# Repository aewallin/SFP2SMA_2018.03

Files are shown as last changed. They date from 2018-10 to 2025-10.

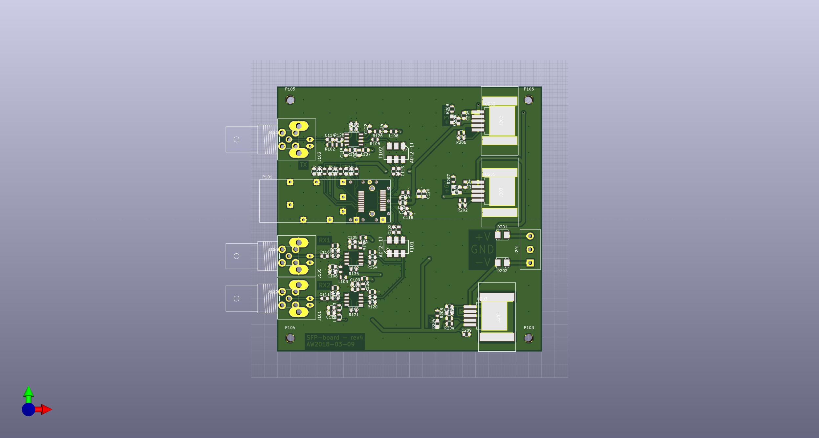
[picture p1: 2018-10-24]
doc/top_view.jpg

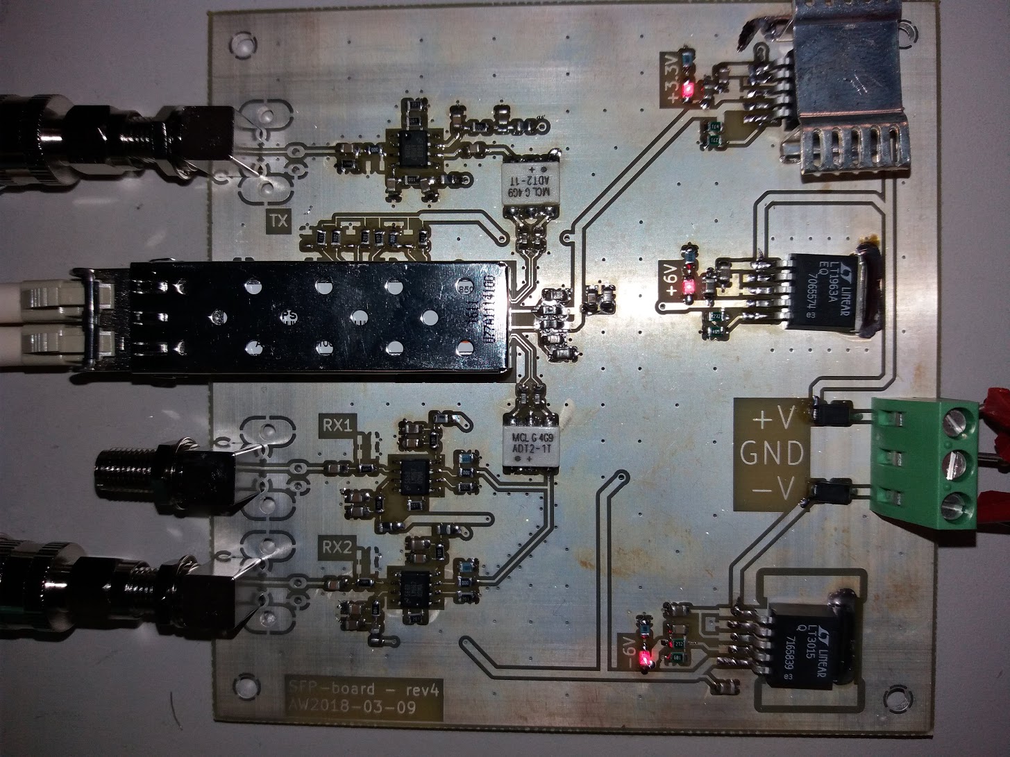
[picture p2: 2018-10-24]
doc/SFP-board_v4_20180403_162020.jpg

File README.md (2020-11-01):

# SFP-2-SMA Board, 2018-03

This is a simple board for opto/electric and electro/optic conversion of RF-signals (up to maybe 500 MHz)
using telecom SFP transcievers. The board can be fitted with either BNC or SMA connectors. It has one input
which modulates the TX pins of the SFP, and two identical outputs that represent the signal on the RX pins
of the SFP.

Some notes from 2018-04: http://www.anderswallin.net/2018/04/500-mhz-sfp-board-v4/

## Circuit description

Differential (100 Ohm) signals on the TX+/TX- and RX+/RX- pins of the SFP are converted to
single-ended (50 Ohm) signals using Mini-Circuits ADT2-1T transformers.
LMH6702 op-amps amplify/buffer all signals.
LT1963 and LT3015 low-noise LDOs provide +3V3, +6V, and -6V DC rails.
The +3V3 LDO needs heat-sinking, especially with long-range SFPs that have high current draw.

## Links to other SFP-boards

- https://osmocom.org/projects/misc-hardware/wiki/Sfp-experimenter
- https://osmocom.org/projects/misc-hardware/wiki/Sfp-breakout
- https://vksdr.com/pmod

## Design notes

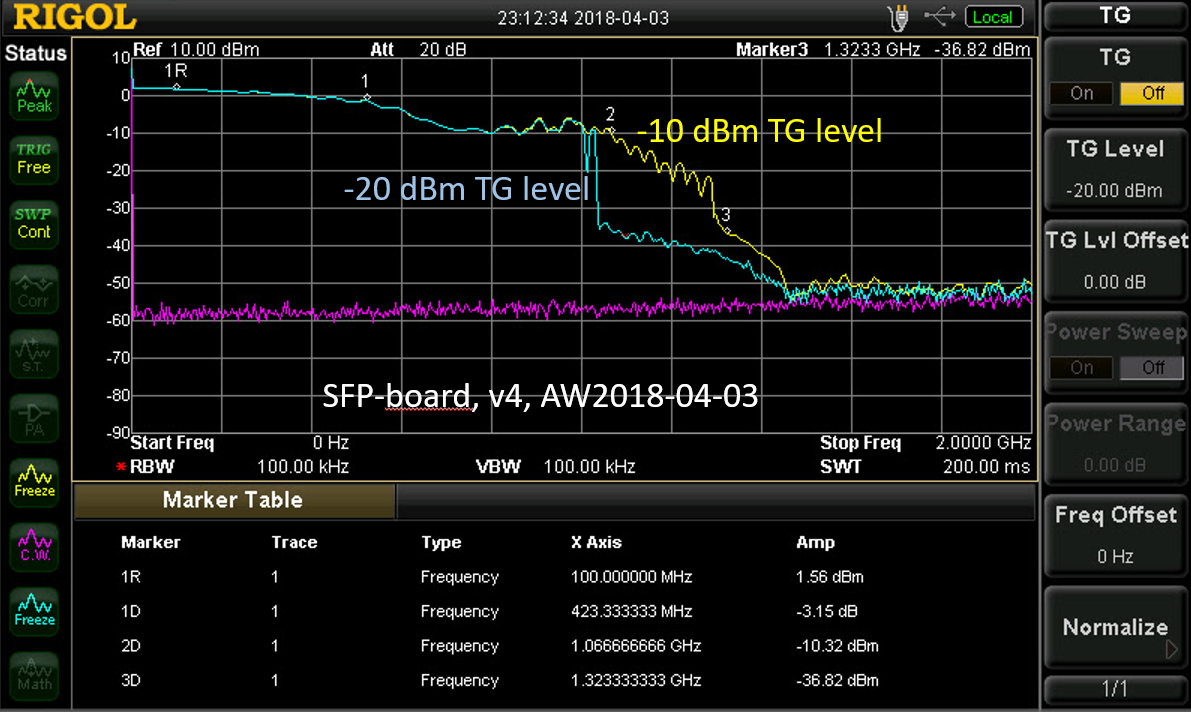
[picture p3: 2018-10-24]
doc/SFP-board_v4_2018-04-03.png

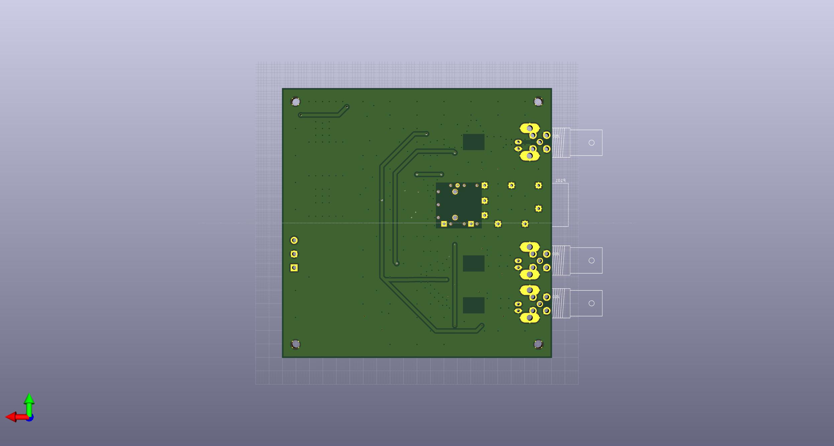
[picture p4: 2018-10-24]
doc/bot_view.jpg

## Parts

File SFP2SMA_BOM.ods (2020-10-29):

Description | QTY | price | total | Digikey/Farnell
Resistors, SMD 0805 | 20 |  | 0
Capacitors, SMD 0805 | 20 |  | 0
LED, SMD 0805 | 6 | 0.109 | 0.654 | 2463991
Inductor, SMD 0805 | 8 |  | 0
Diode, DO214B | 3 | 0.3 | 0.9 | 9555986
Heatsink, D2PAK | 1 | 1.66 | 1.66 | 4302436
SMA connectors | 3 | 4.97 | 14.91 | 2293854
DC-connector, 4pole | 1 | 1.89 | 1.89 | 277-1249-ND
SFP-connector | 1 | 1.64 | 1.64 | 1654067
SFP-cage | 1 | 1.55 | 1.55 | 1849934
RF Transformer, ADT2-1T | 2 | 8 | 16 | ADT2-1T, mini-circuits | https://www.minicircuits.com/WebStore/dashboard.html?model=ADT2-1T
Op-amp LMH6702 | 3 | 3.29 | 9.87 | LMH6702MA/NOPB-ND
hex inverter 74HC14 | 1 | 0.34 | 0.34 | 296-8234-1-ND
Vreg adjustable | 1 | 5.56 | 5.56 | LT1963AEQ#TRPBFCT-ND
Vreg neg, adjustable | 1 | 6.06 | 6.06 | LT3015EQ#PBF-ND
Vreg +3.3V | 1 | 5.56 | 5.56 | LT1963AEQ-3.3#TRPBFCT-ND
 |  | SUM | 66.594

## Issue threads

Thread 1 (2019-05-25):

revise schematic with kicad-library symbols/footprints

aewallin, 2019-05-25:
Since the original design many of the symbols and footprints used are now part of the standard kicad libraries.

Ideally the schematic and board should be revised to use the standard library symbols and footprints.

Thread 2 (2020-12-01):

provide POWER LED at the front panel

aewallin, 2020-12-01:
Currently all three front-panel LEDs are OFF when the box is operating.
(TX fault, RX LOS, and mod_abs).
It would be good to provide a power LED to show that the box receives DC-power and is ok.

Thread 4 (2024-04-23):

BOM question

htgrp, 2024-04-23:
Hey I hope you are well. I am not an electrical engineer so forgive me for this question. I wanted to test your project as part of a LiFi project I am working on. I was hoping to send your part to a PCB assemble service but they needed the BOM in a specific format. Do you by chance have a BOM structured closer to this one?

[Copy of Template BOM_PCBWay.xlsx](https://github.com/aewallin/SFP2SMA_2018.03/files/15078407/Copy.of.Template.BOM_PCBWay.xlsx)

aewallin, 2024-04-25:
Hi, there are BOM-plugins for KiCAD, but I am not using them at the moment.
Another task would be to update this design to use the latest kicad-version, and possibly standard library symbols and footprints.
If you make some progress on this - let me know or send a pull request. I probably won't have time to work on this at the moment.

htgrp, 2024-04-25:
Hey thanks so much for getting back to me. I figured as much. I'm not super proficient in the application. The application told me it would update it to the new Kicad when I saved it. Here are the files it created at that time and also I did some work on the BOM. I had some help with it from PCB assembly service JLCPCB. It looked like they has the wrong version of the micro-circuits chip so I swapped that out. Im also attaching my finalized BOM (I hope) and the JLCPCB BOM. Im not sure if any of it useful but if it is great.
[BOM.xlsx](https://github.com/aewallin/SFP2SMA_2018.03/files/15122776/BOM.xlsx)
[PCBWay-Bom.xlsx](https://github.com/aewallin/SFP2SMA_2018.03/files/15122777/PCBWay-Bom.xlsx)
[sfp_v4-latest.zip](https://github.com/aewallin/SFP2SMA_2018.03/files/15122779/sfp_v4-latest.zip)

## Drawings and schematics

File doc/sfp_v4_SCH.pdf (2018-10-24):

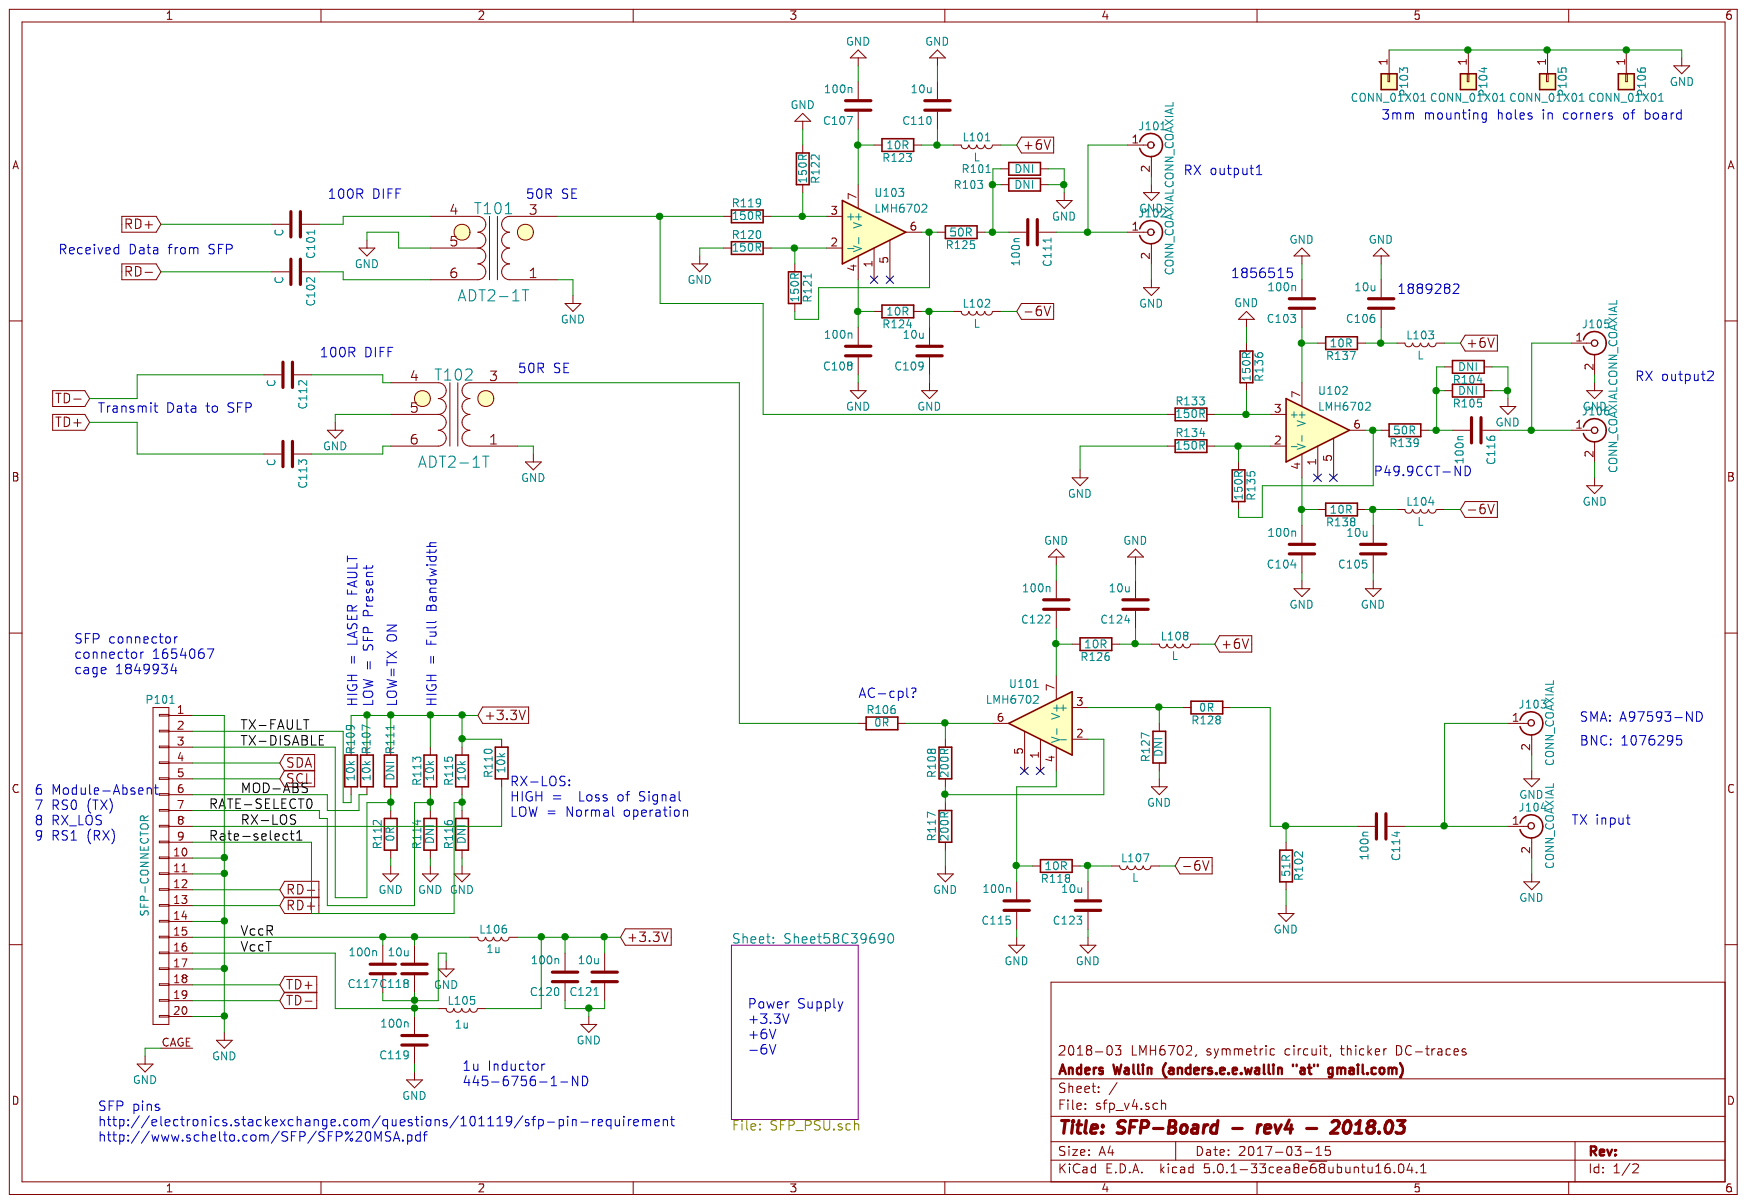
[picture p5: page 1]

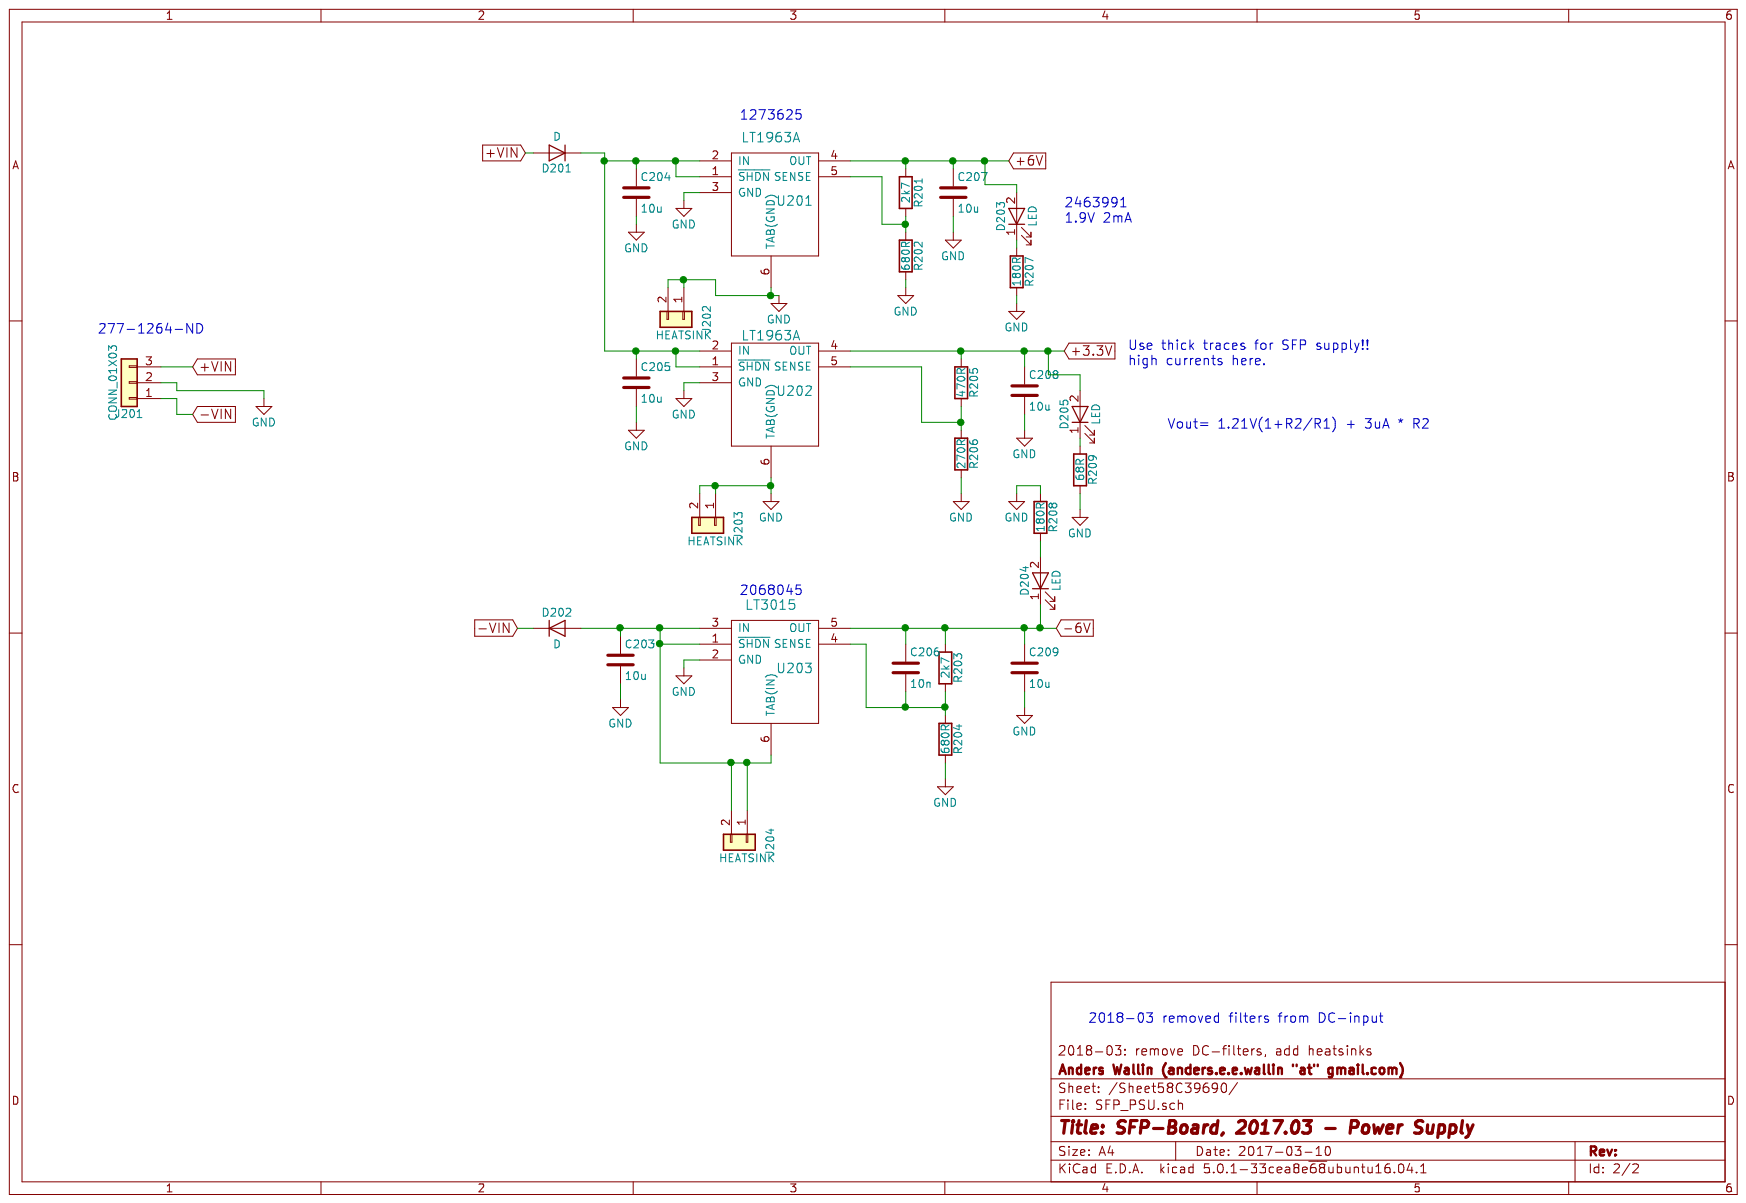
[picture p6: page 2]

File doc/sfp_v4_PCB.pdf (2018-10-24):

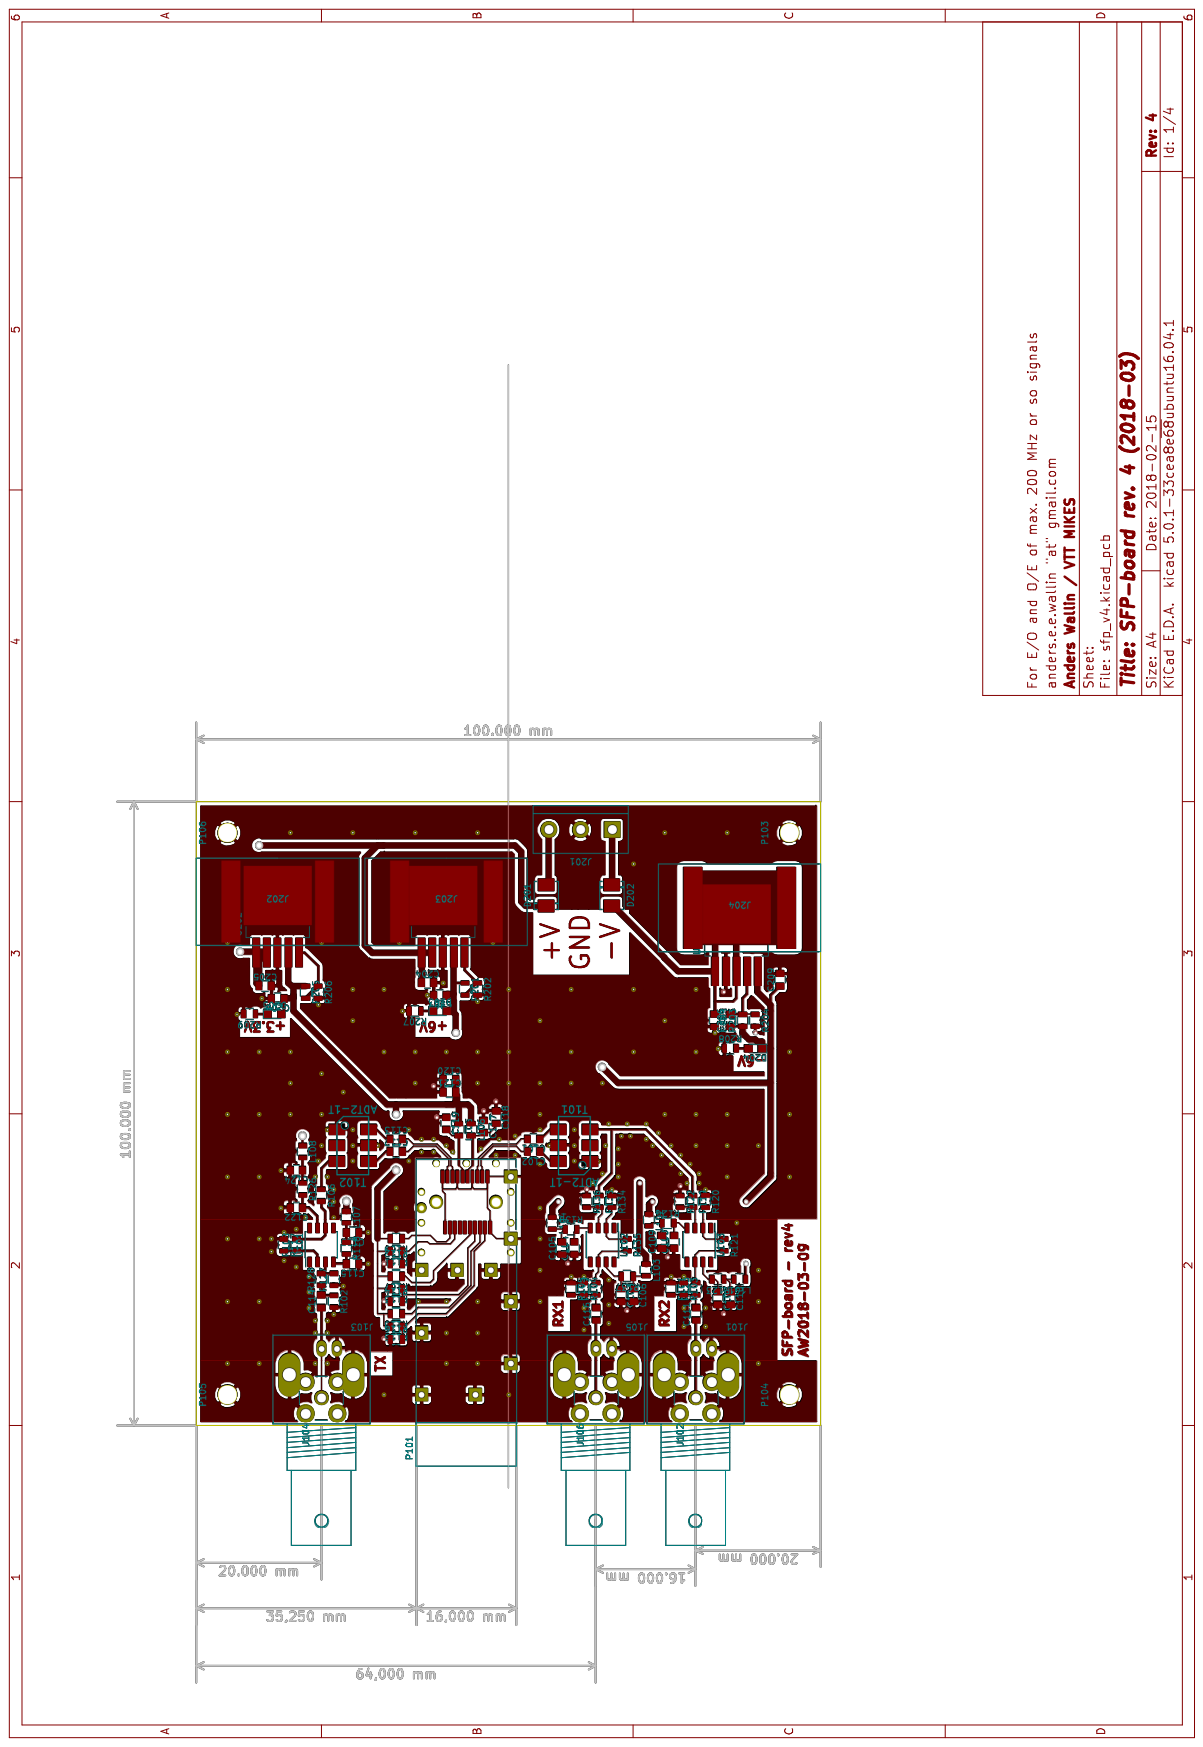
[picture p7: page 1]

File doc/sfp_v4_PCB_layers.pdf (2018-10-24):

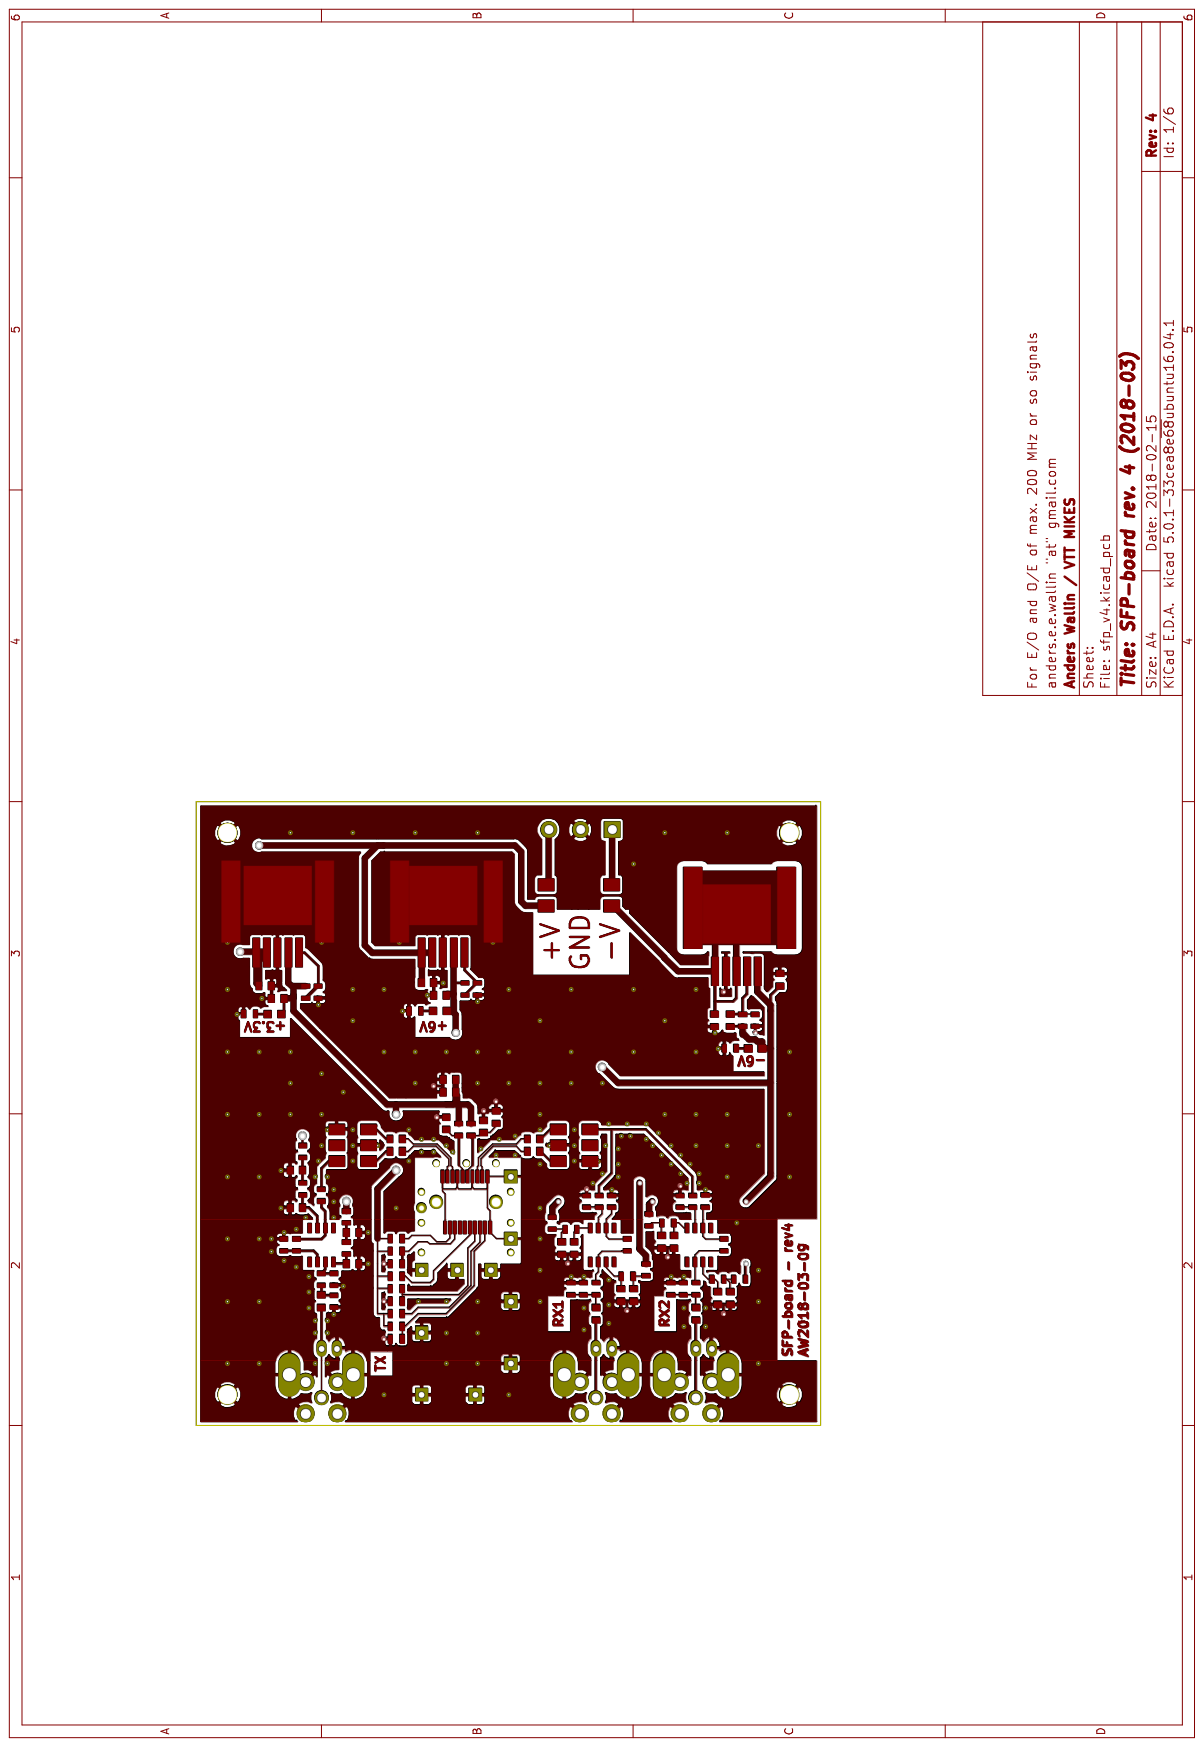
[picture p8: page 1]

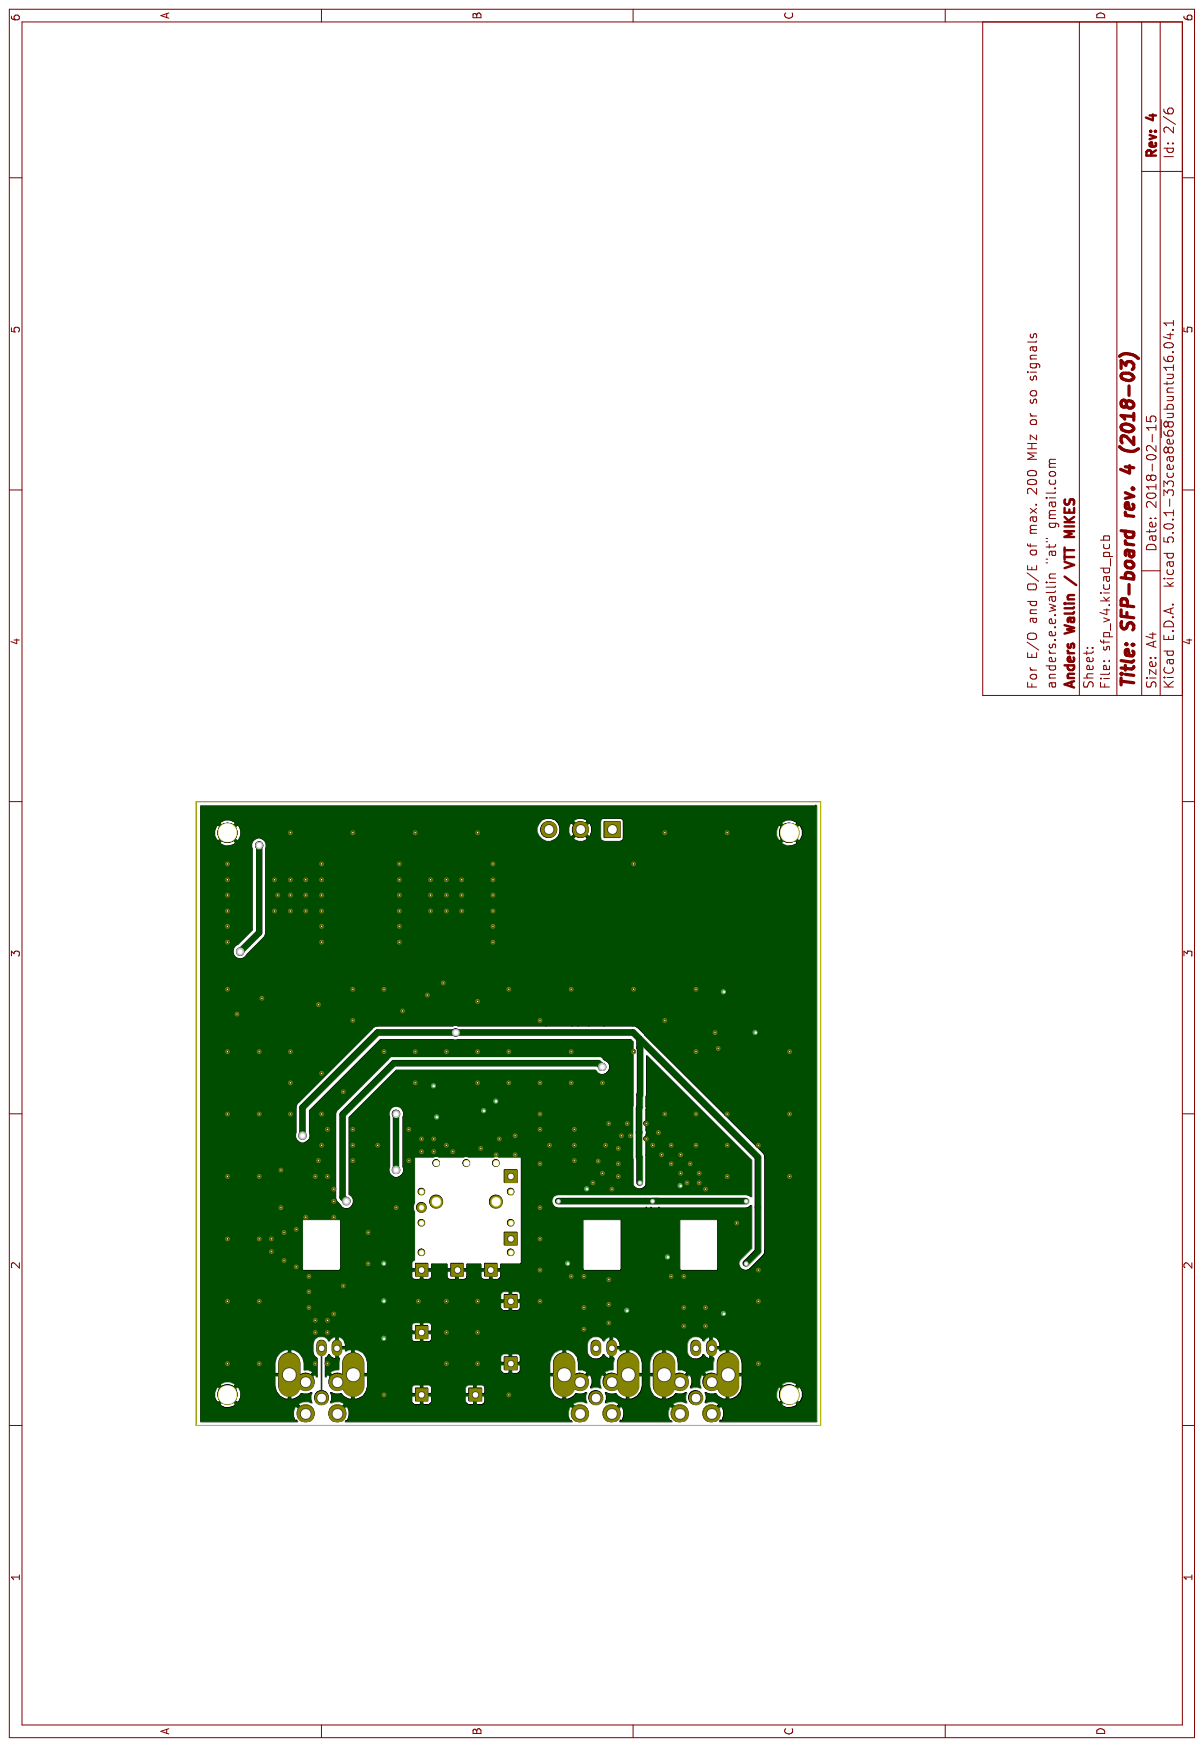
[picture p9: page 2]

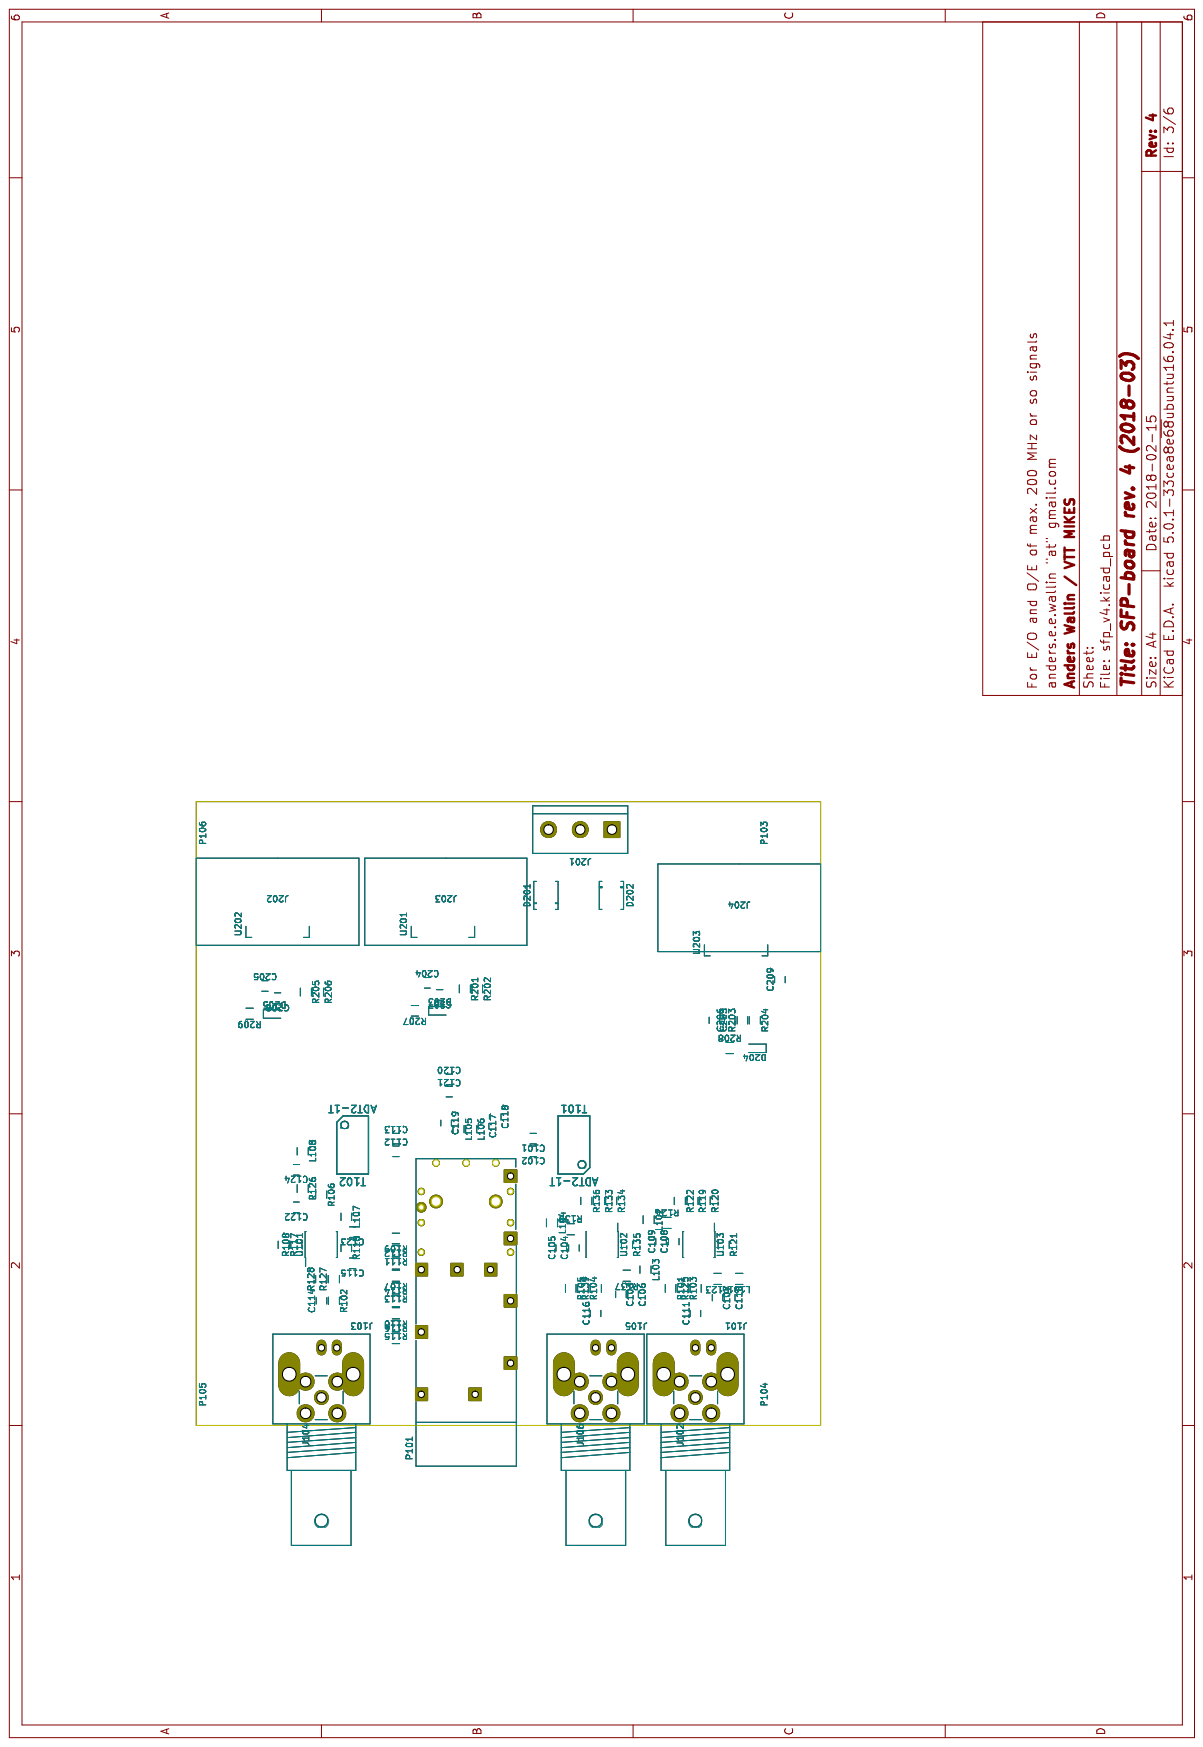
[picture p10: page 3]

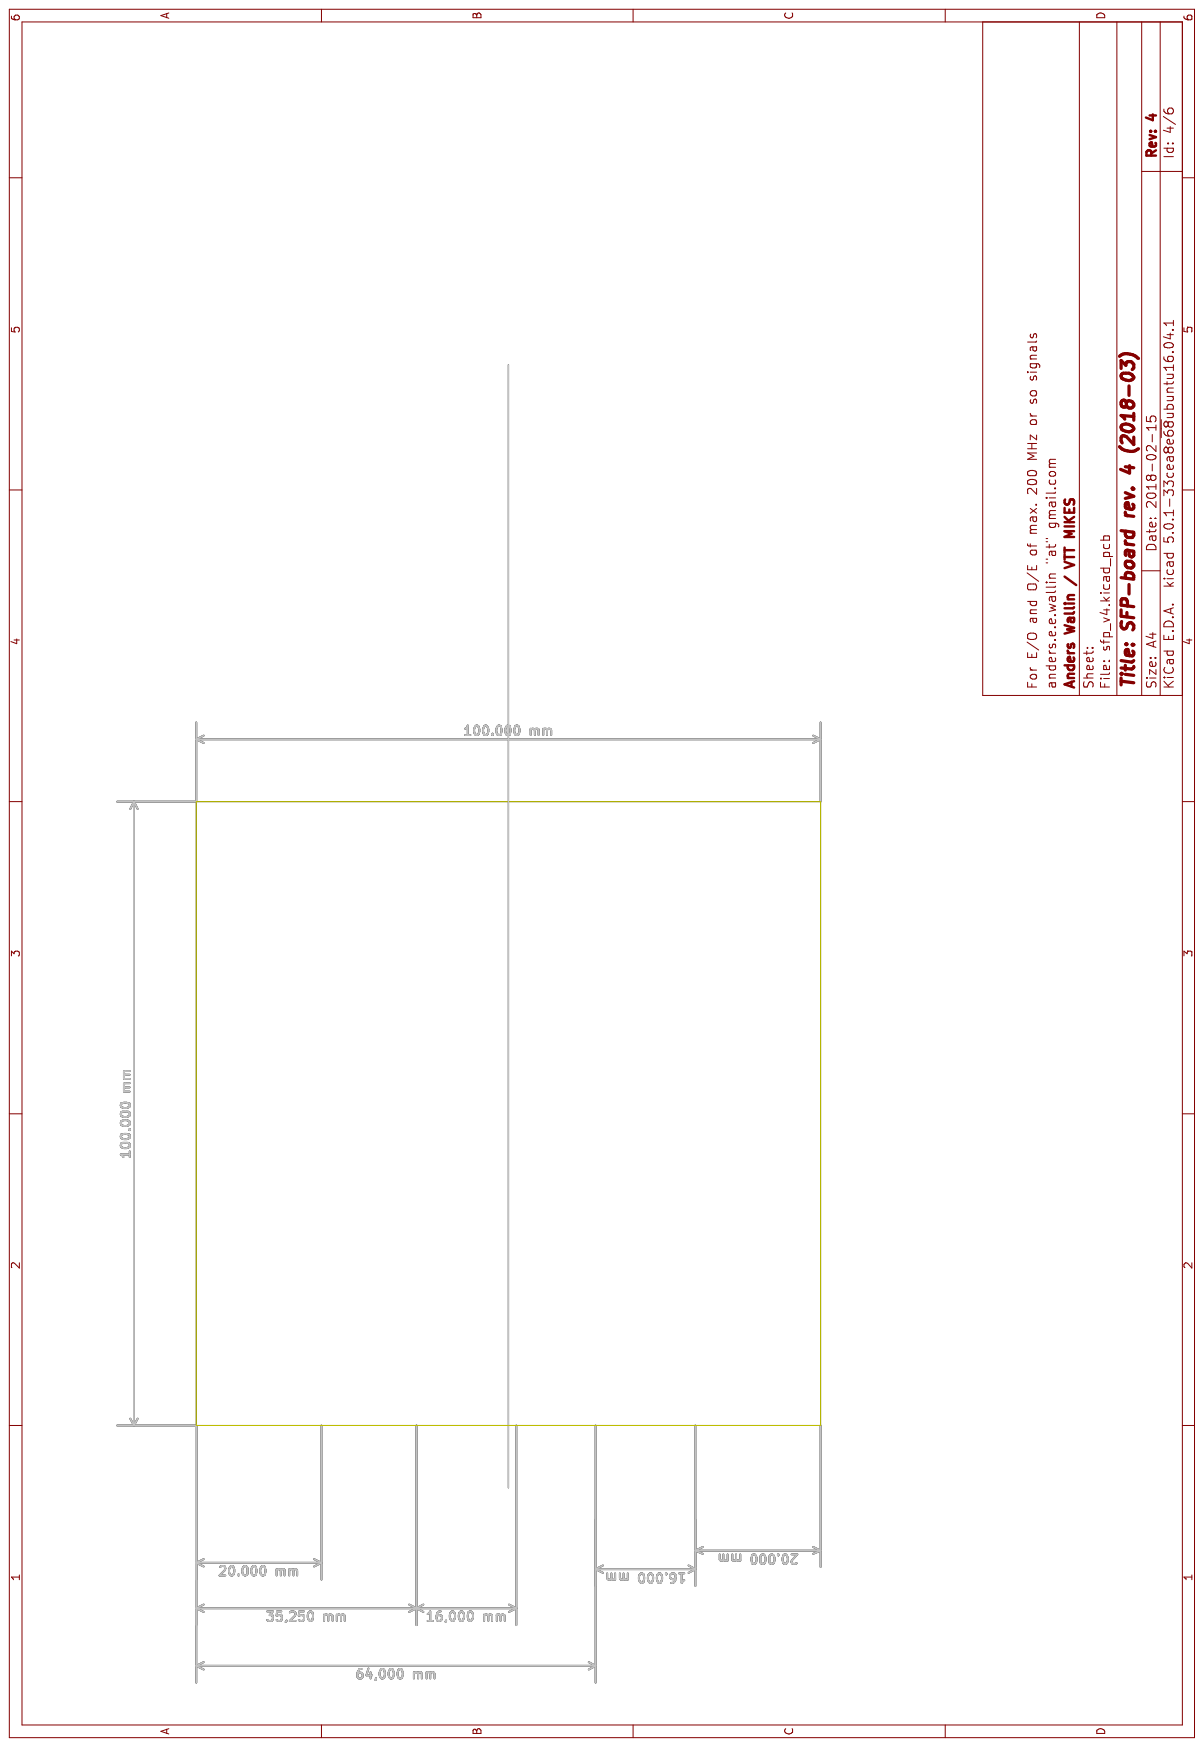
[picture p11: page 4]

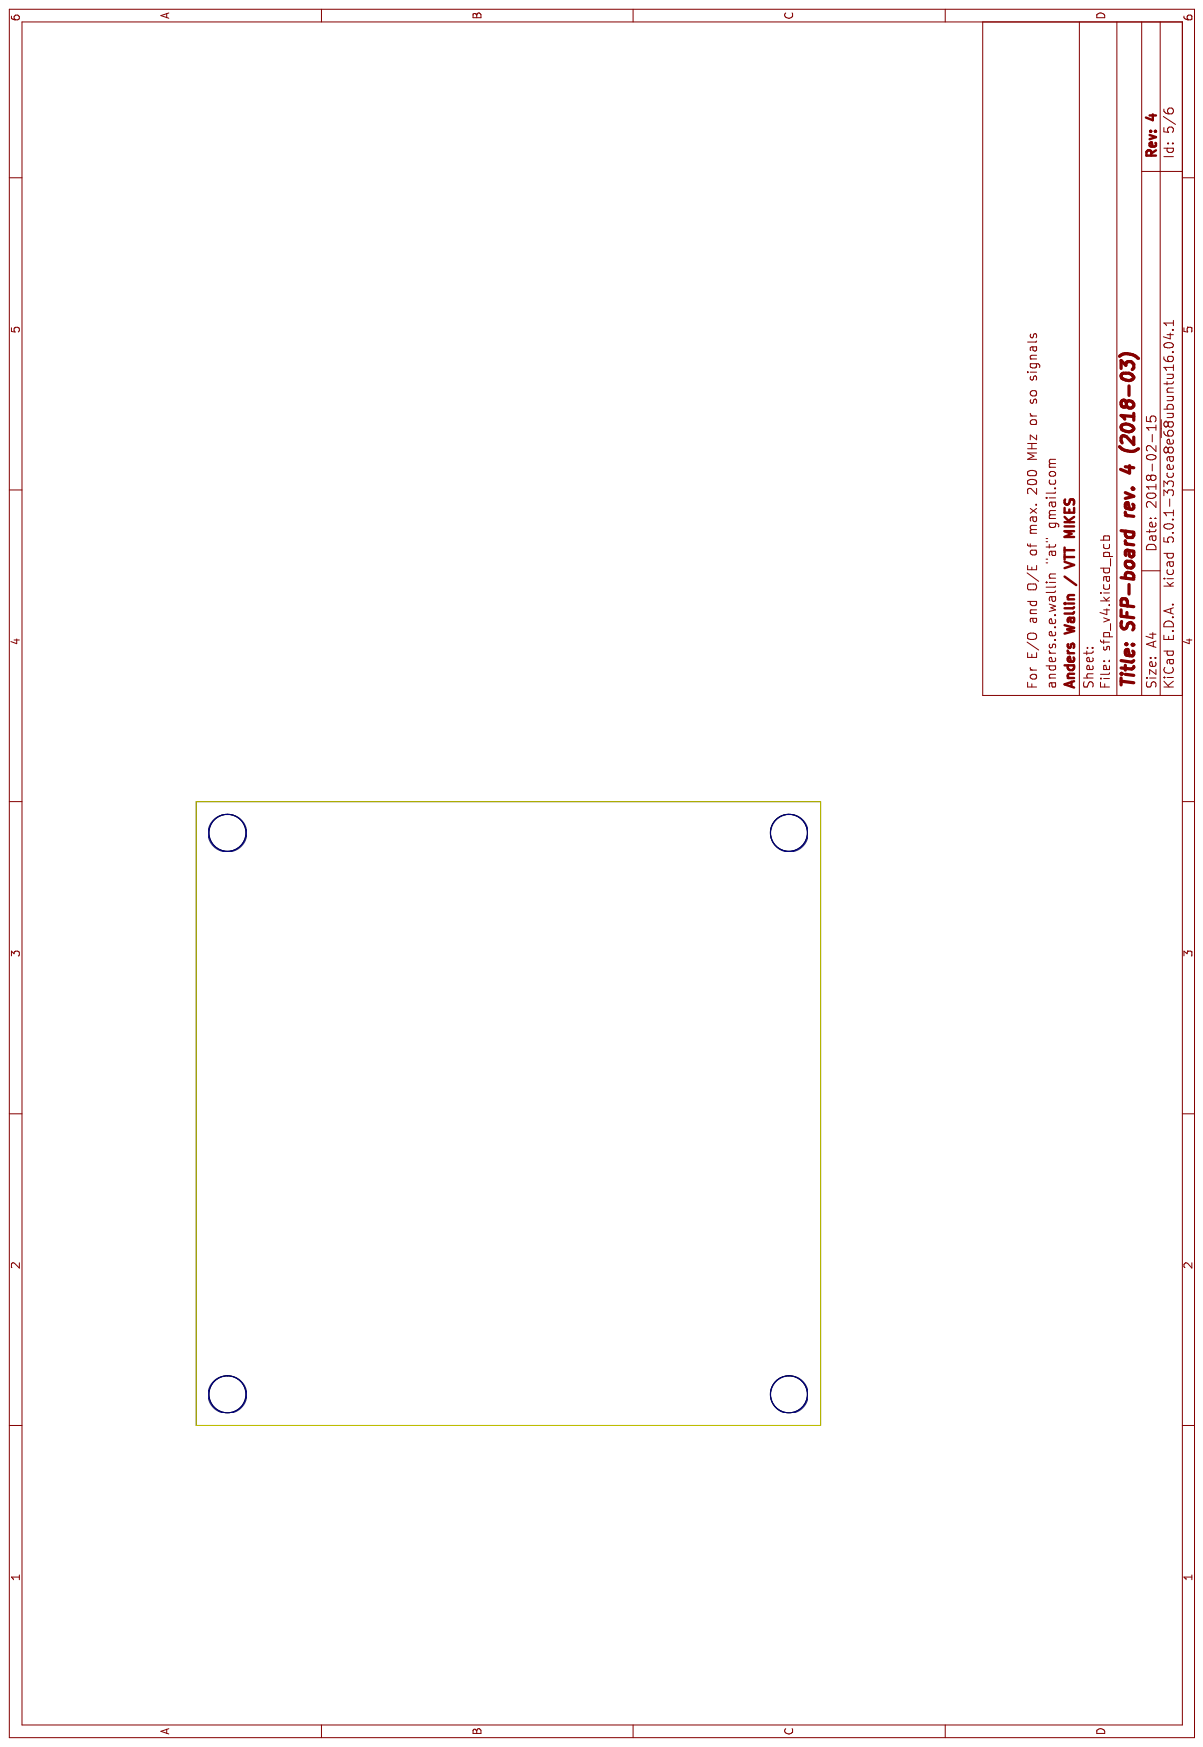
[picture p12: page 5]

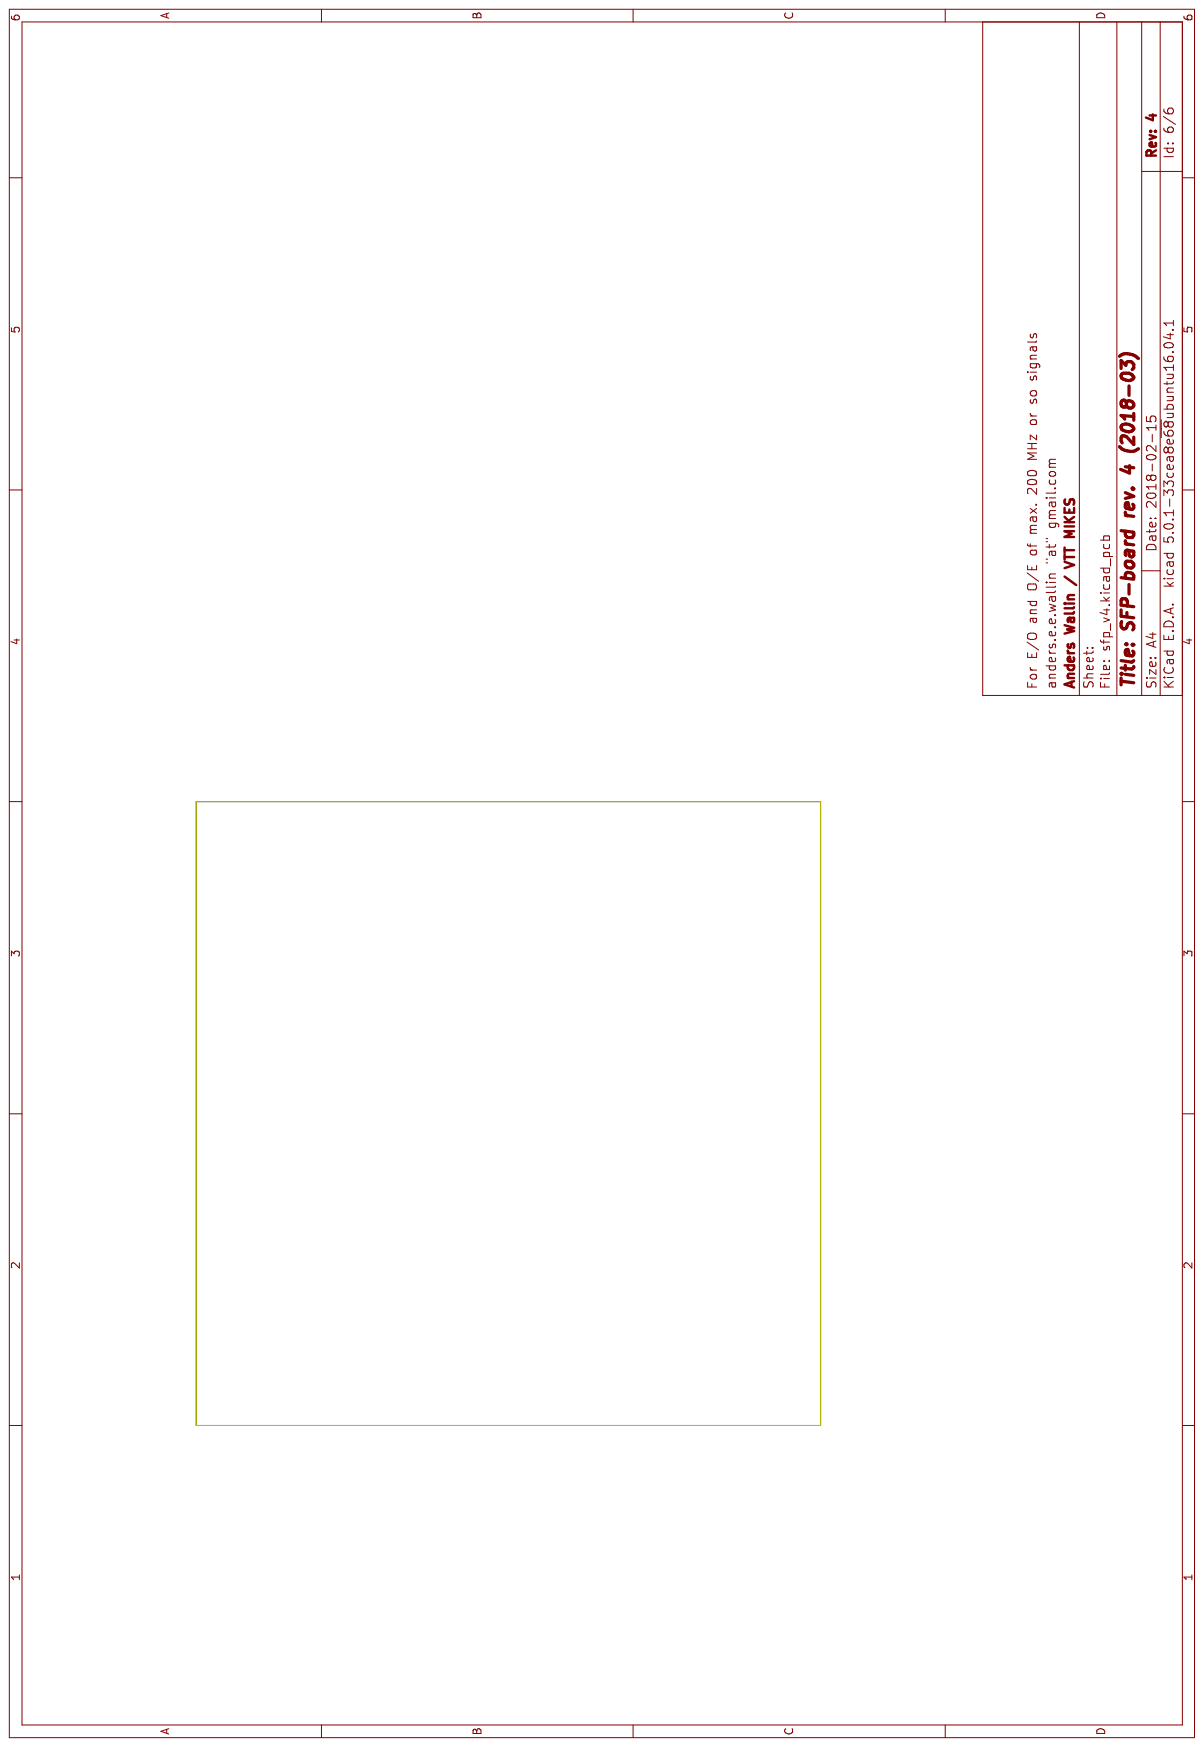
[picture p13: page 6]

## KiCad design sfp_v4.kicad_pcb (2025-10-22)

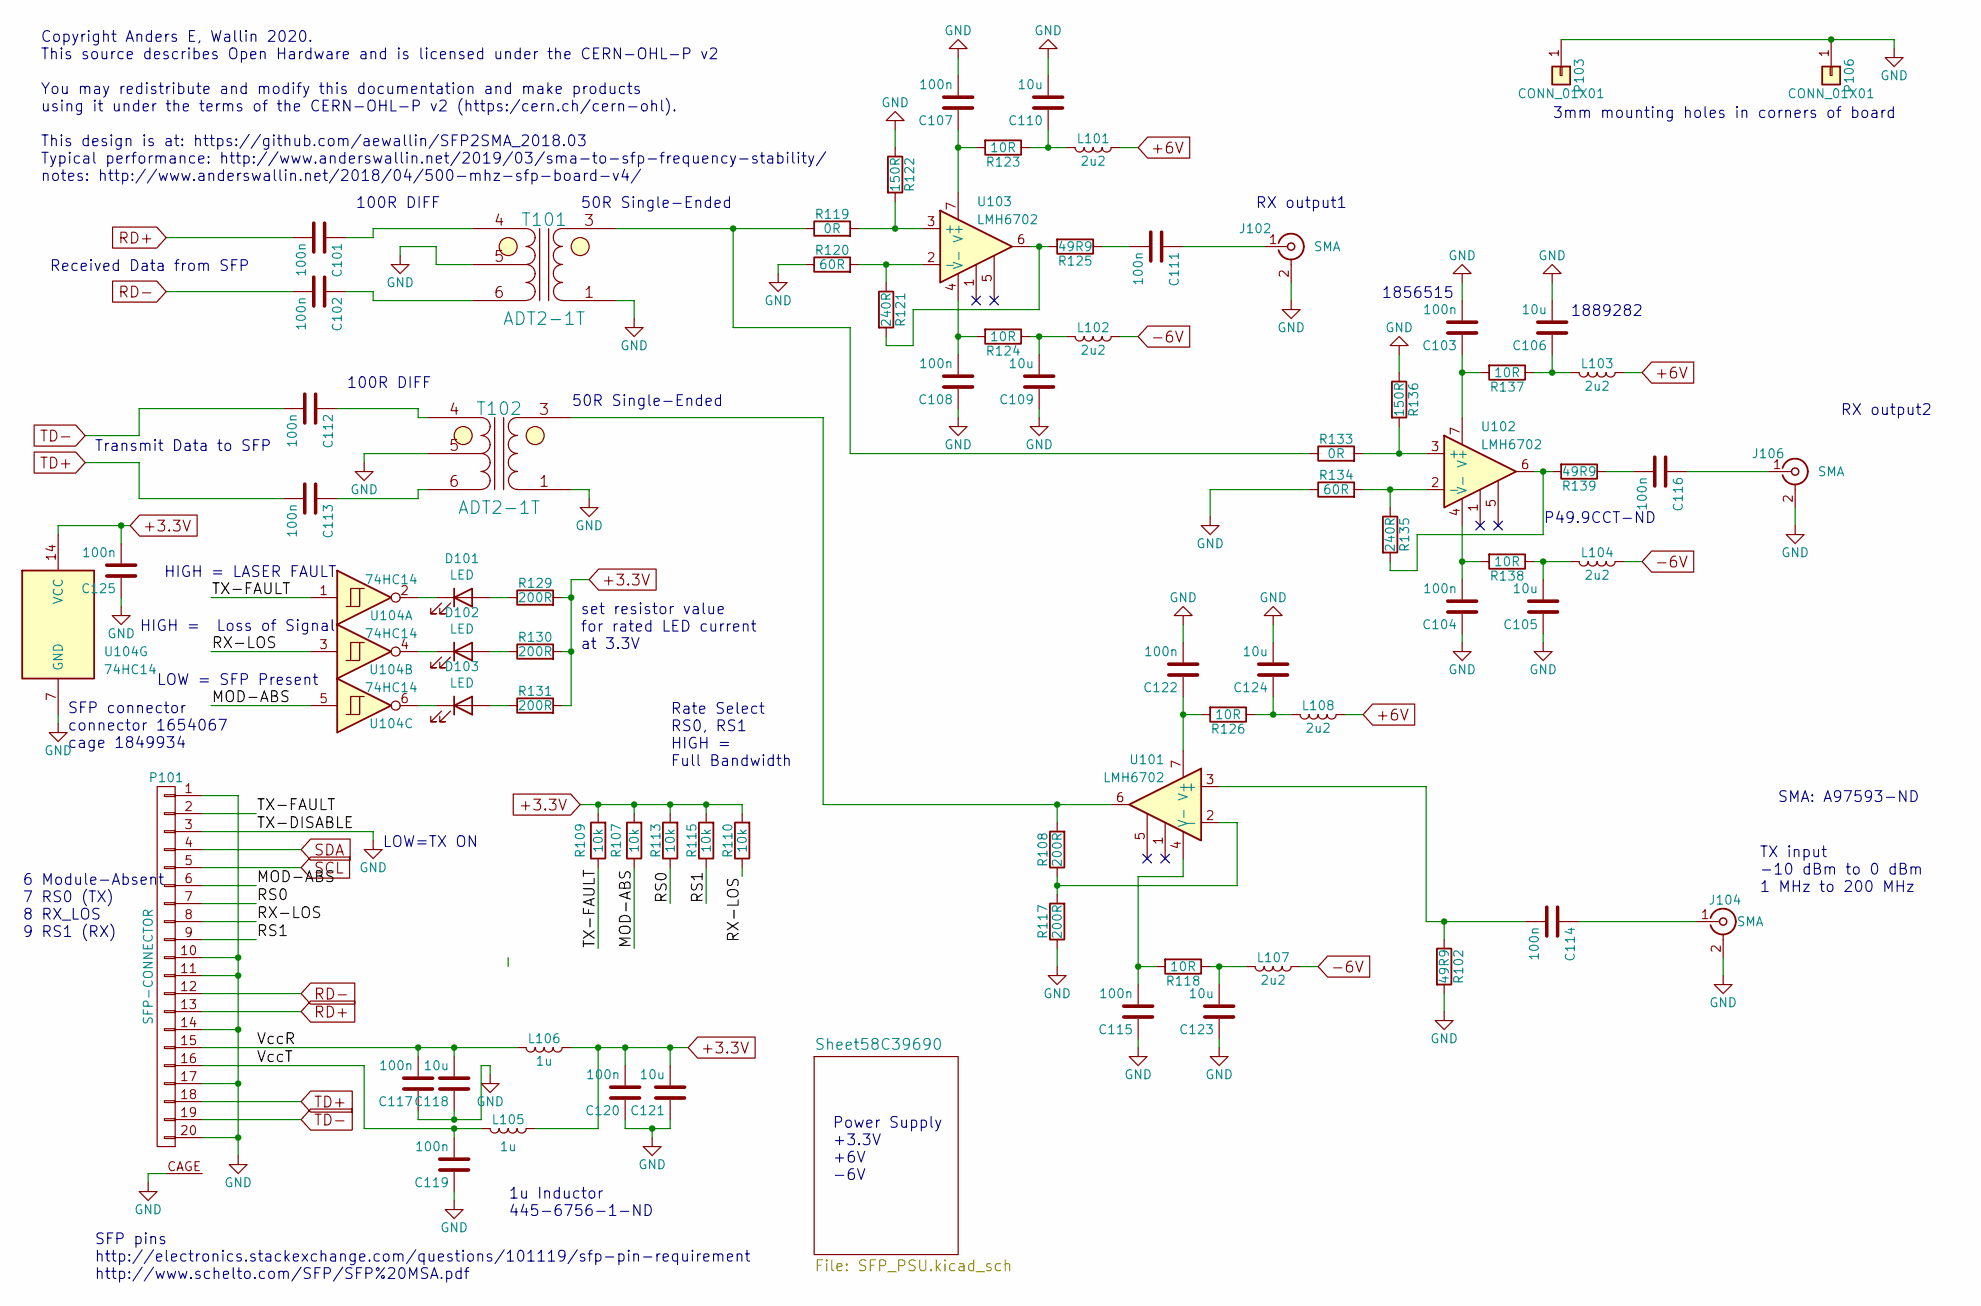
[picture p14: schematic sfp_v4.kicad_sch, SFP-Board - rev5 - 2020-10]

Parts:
C101, C102, C103, C104, C107, C108, C111, C112, C113, C114, C115, C116, C117, C119, C120, C122: 100n; C_0805
C105, C106, C109, C110, C118, C121, C123, C124: 10u; C_0805
C125: 100n; C_0805_2012Metric
D101, D102, D103: LED; LED_0805_2012Metric
J102, J104, J106: SMA; SMA_Molex_73251-2200_Horizontal
L101, L102, L103, L104, L107, L108: 2u2; R_0805
L105, L106: 1u; R_0805
P101: SFP-CONNECTOR; Connector_SFP_and_Cage
P103, P106: CONN_01X01; MountingHole_3mm
R102, R125, R139: 49R9; R_0805
R107, R109, R110, R113, R115: 10k; R_0805
R108, R117: 200R; R_0805
R118, R123, R124, R126, R137, R138: 10R; R_0805
R119, R133: 0R; R_0805
R120, R134: 60R; R_0805
R121, R135: 240R; R_0805
R122, R136: 150R; R_0805
R129, R130, R131: 200R; R_0805_2012Metric
T101, T102: ADT2-1T; MiniCircuits_CD542
U101, U102, U103: LMH6702; SOIC-8_3.9x4.9mm_Pitch1.27mm
U104: 74HC14; TSSOP-14_4.4x5mm_P0.65mm

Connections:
+3.3V: C120.2, C121.2, C125.2, L105.1, L106.1, R107.2, R109.2, R110.2, R113.2, R115.2, R129.2, R130.2, R131.2, U104.14 (VCC); also elsewhere on the board
+6V: L101.1, L103.1, L108.1; also elsewhere on the board
-6V: L102.1, L104.1, L107.1; also elsewhere on the board
/MOD-ABS: P101.6, R107.1, U104.5
/RS0: P101.7, R113.1
/RS1: P101.9, R115.1
/RX-LOS: P101.8, R110.1, U104.3
/TX-FAULT: P101.2, R109.1, U104.1
/VccR: C117.2, C118.2, L106.2, P101.15
/VccT: C119.2, L105.2, P101.16
GND: C103.2, C104.1, C105.1, C106.2, C107.2, C108.1, C109.1, C110.2, C115.1, C117.1, C118.1, C119.1, C120.1, C121.1, C122.2, C123.1, C124.2, C125.1, J102.2 (Ext), J104.2 (Ext), J106.2 (Ext), P101.1, P101.3, P101.10, P101.11, P101.14, P101.17, P101.20, P101.CAGE, P103.1, P106.1, R102.2, R117.1, R120.1, R122.1, R134.1, R136.1, T101.1 (PR), T101.5 (SEC_CT), T102.1 (PR), T102.5 (SEC_CT), U104.7 (GND); also elsewhere on the board
unnamed: C101.1, T101.4 (SEC_DOT)
unnamed: C102.1, T101.6 (SEC)
unnamed: C103.1, R137.2, U102.7 (V+)
unnamed: C104.2, R138.2, U102.4 (V-)
unnamed: C105.2, L104.2, R138.1
unnamed: C106.1, L103.2, R137.1
unnamed: C107.1, R123.2, U103.7 (V+)
unnamed: C108.2, R124.2, U103.4 (V-)
unnamed: C109.2, L102.2, R124.1
unnamed: C110.1, L101.2, R123.1
unnamed: C111.1, J102.1 (In)
unnamed: C111.2, R125.1
unnamed: C112.1, T102.4 (SEC_DOT)
unnamed: C113.1, T102.6 (SEC)
unnamed: C114.1, J104.1 (In)
unnamed: C114.2, R102.1, U101.3 (+)
unnamed: C115.2, R118.2, U101.4 (V-)
unnamed: C116.1, J106.1 (In)
unnamed: C116.2, R139.1
unnamed: C122.1, R126.2, U101.7 (V+)
unnamed: C123.2, L107.2, R118.1
unnamed: C124.1, L108.2, R126.1
unnamed: D101.1 (K), U104.2
unnamed: D101.2 (A), R129.1
unnamed: D102.1 (K), U104.4
unnamed: D102.2 (A), R130.1
unnamed: D103.1 (K), U104.6
unnamed: D103.2 (A), R131.1
unnamed: R108.1, R117.2, U101.2 (-)
unnamed: R108.2, T102.3 (PR_DOT), U101.6
unnamed: R119.1, R133.1, T101.3 (PR_DOT)
unnamed: R119.2, R122.2, U103.3 (+)
unnamed: R120.2, R121.1, U103.2 (-)
unnamed: R121.2, R125.2, U103.6
unnamed: R133.2, R136.2, U102.3 (+)
unnamed: R134.2, R135.1, U102.2 (-)
unnamed: R135.2, R139.2, U102.6
RD+: C101.2, P101.13
RD-: C102.2, P101.12
SCL: P101.5
SDA: P101.4
TD+: C113.2, P101.18
TD-: C112.2, P101.19

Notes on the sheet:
100R DIFF
RX output2
1889282
P49.9CCT-ND
HIGH = LASER FAULT
LOW = SFP Present
Transmit Data to SFP
RX output1
SFP connector connector 1654067 cage 1849934
Received Data from SFP
Power Supply +3.3V +6V -6V
50R Single-Ended
Rate Select RS0, RS1 HIGH = Full Bandwidth
6 Module-Absent 7 RS0 (TX) 8 RX_LOS 9 RS1 (RX)
SFP pins http://electronics.stackexchange.com/questions/101119/sfp-pin-requirement http://www.schelto.com/SFP/SFP%20MSA.pdf
1u Inductor 445-6756-1-ND
HIGH = Loss of Signal
LOW=TX ON
Copyright Anders E, Wallin 2020. This source describes Open Hardware and is licensed under the CERN-OHL-P v2 You may redistribute and modify this documentation and make products using it under the terms of the CERN-OHL-P v2 (https:/cern.ch/cern-ohl). This design is at: https://github.com/aewallin/S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
set resistor value for rated LED current at 3.3V
SMA: A97593-ND
1856515
TX input -10 dBm to 0 dBm 1 MHz to 200 MHz
3mm mounting holes in corners of board

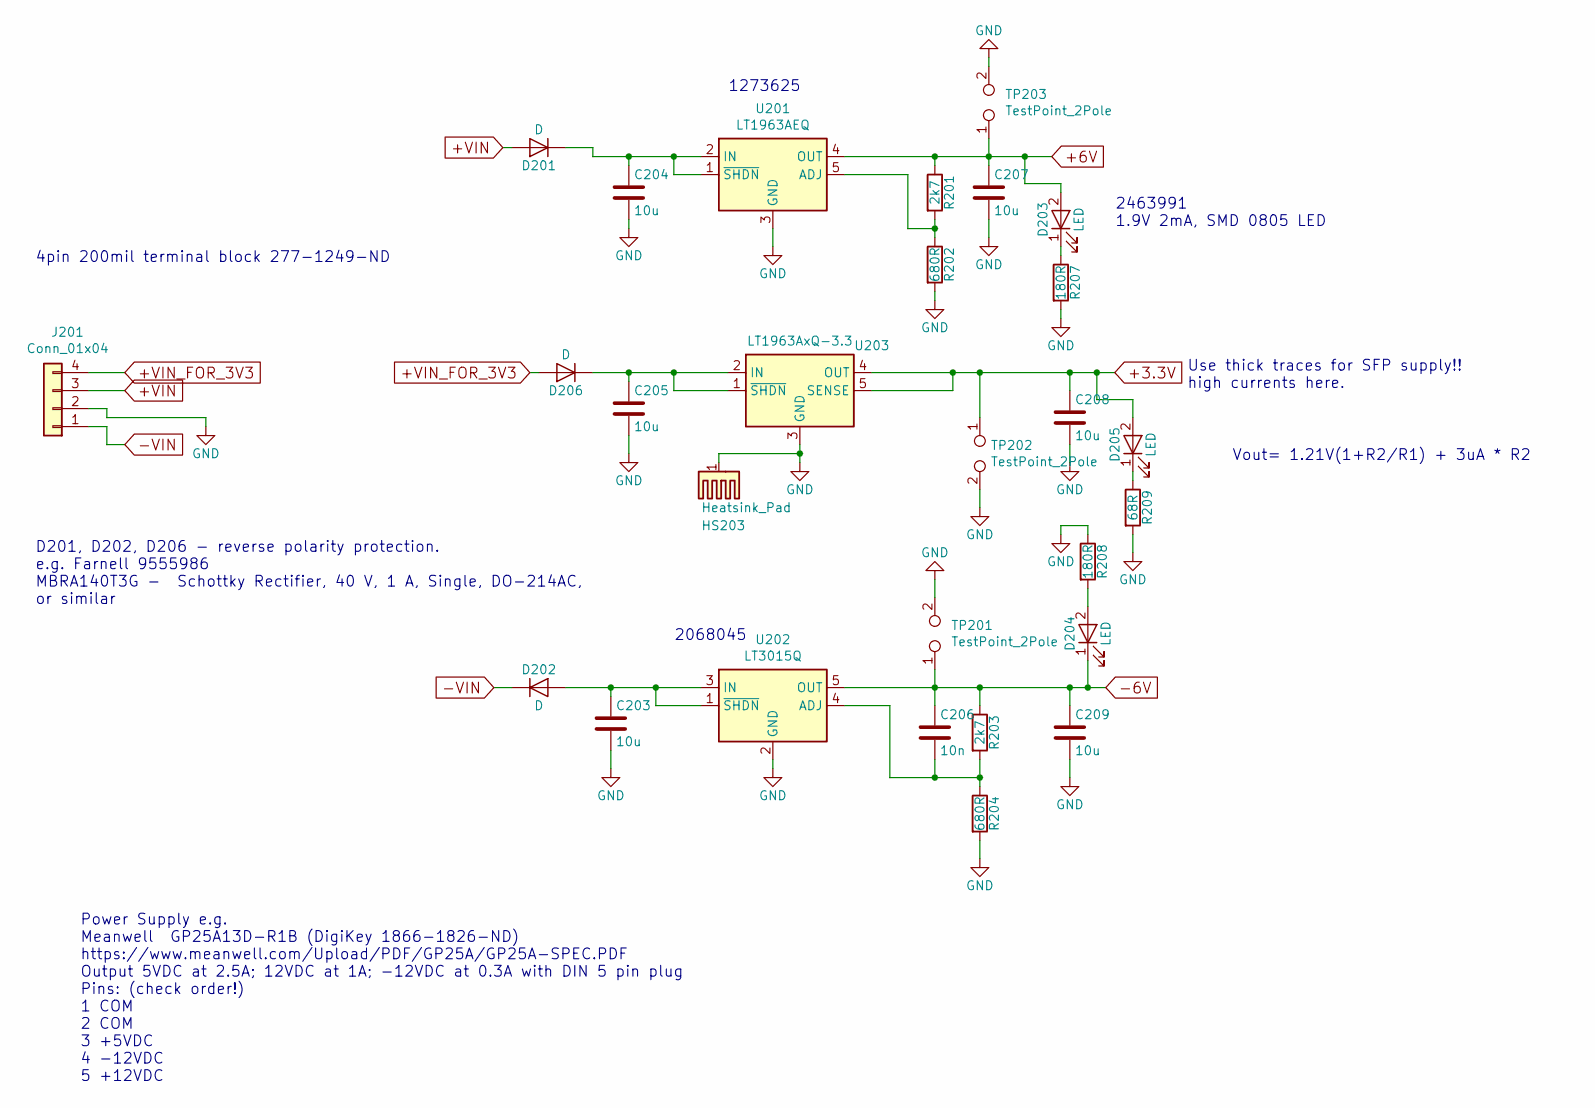
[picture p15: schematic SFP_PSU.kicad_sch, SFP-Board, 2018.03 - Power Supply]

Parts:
C203, C204, C205, C207, C208, C209: 10u; C_0805
C206: 10n; C_0805
D201, D202, D206: D; DIODE_DO-214BA
D203, D204, D205: LED; LED_0805
HS203: Heatsink_Pad; Heatsink_Fischer_FK24413D2PAK_26x13mm
J201: Conn_01x04; TerminalBlock_bornier-4_P5.08mm
R201, R203: 2k7; R_0805
R202, R204: 680R; R_0805
R207, R208: 180R; R_0805
R209: 68R; R_0805
TP201, TP202, TP203: TestPoint_2Pole; TestPoint_2Pads_Pitch2.54mm_Drill0.8mm
U201: LT1963AEQ; TO-263-5_TabPin3
U202: LT3015Q; TO-263-5_TabPin3
U203: LT1963AxQ-3.3; TO-263-5_TabPin3

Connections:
+3.3V: C208.1, D205.2 (A), TP202.1, U203.4 (OUT), U203.5 (SENSE); also elsewhere on the board
+6V: C207.1, D203.2 (A), R201.1, TP203.1, U201.4 (OUT); also elsewhere on the board
+VIN: D201.2 (A), J201.3
+VIN_FOR_3V3: D206.2 (A), J201.4
-6V: C206.1, C209.1, D204.1 (K), R203.1, TP201.1, U202.5 (OUT); also elsewhere on the board
-VIN: D202.1 (K), J201.1
GND: C203.2, C204.2, C205.2, C207.2, C208.2, C209.2, HS203.1, J201.2, R202.2, R204.2, R207.2, R208.1, R209.2, TP201.2, TP202.2, TP203.2, U201.3 (GND), U202.2 (GND), U203.3 (GND); also elsewhere on the board
unnamed: C203.1, D202.2 (A), U202.1 (~SHDN), U202.3 (IN)
unnamed: C204.1, D201.1 (K), U201.1 (~SHDN), U201.2 (IN)
unnamed: C205.1, D206.1 (K), U203.1 (~SHDN), U203.2 (IN)
unnamed: C206.2, R203.2, R204.1, U202.4 (ADJ)
unnamed: D203.1 (K), R207.1
unnamed: D204.2 (A), R208.2
unnamed: D205.1 (K), R209.1
unnamed: R201.2, R202.1, U201.5 (ADJ)

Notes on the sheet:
Vout= 1.21V(1+R2/R1) + 3uA * R2
2068045
Power Supply e.g. Meanwell GP25A13D-R1B (DigiKey 1866-1826-ND) https://www.meanwell.com/Upload/PDF/GP25A/GP25A-SPEC.PDF Output 5VDC at 2.5A; 12VDC at 1A; -12VDC at 0.3A with DIN 5 pin plug Pins: (check order!) 1 COM 2 COM 3 +5VDC 4 -12VDC 5 +12VDC
D201, D202, D206 - reverse polarity protection. e.g. Farnell 9555986 MBRA140T3G - Schottky Rectifier, 40 V, 1 A, Single, DO-214AC, or similar
2463991 1.9V 2mA, SMD 0805 LED
1273625
4pin 200mil terminal block 277-1249-ND
Use thick traces for SFP supply!! high currents here.

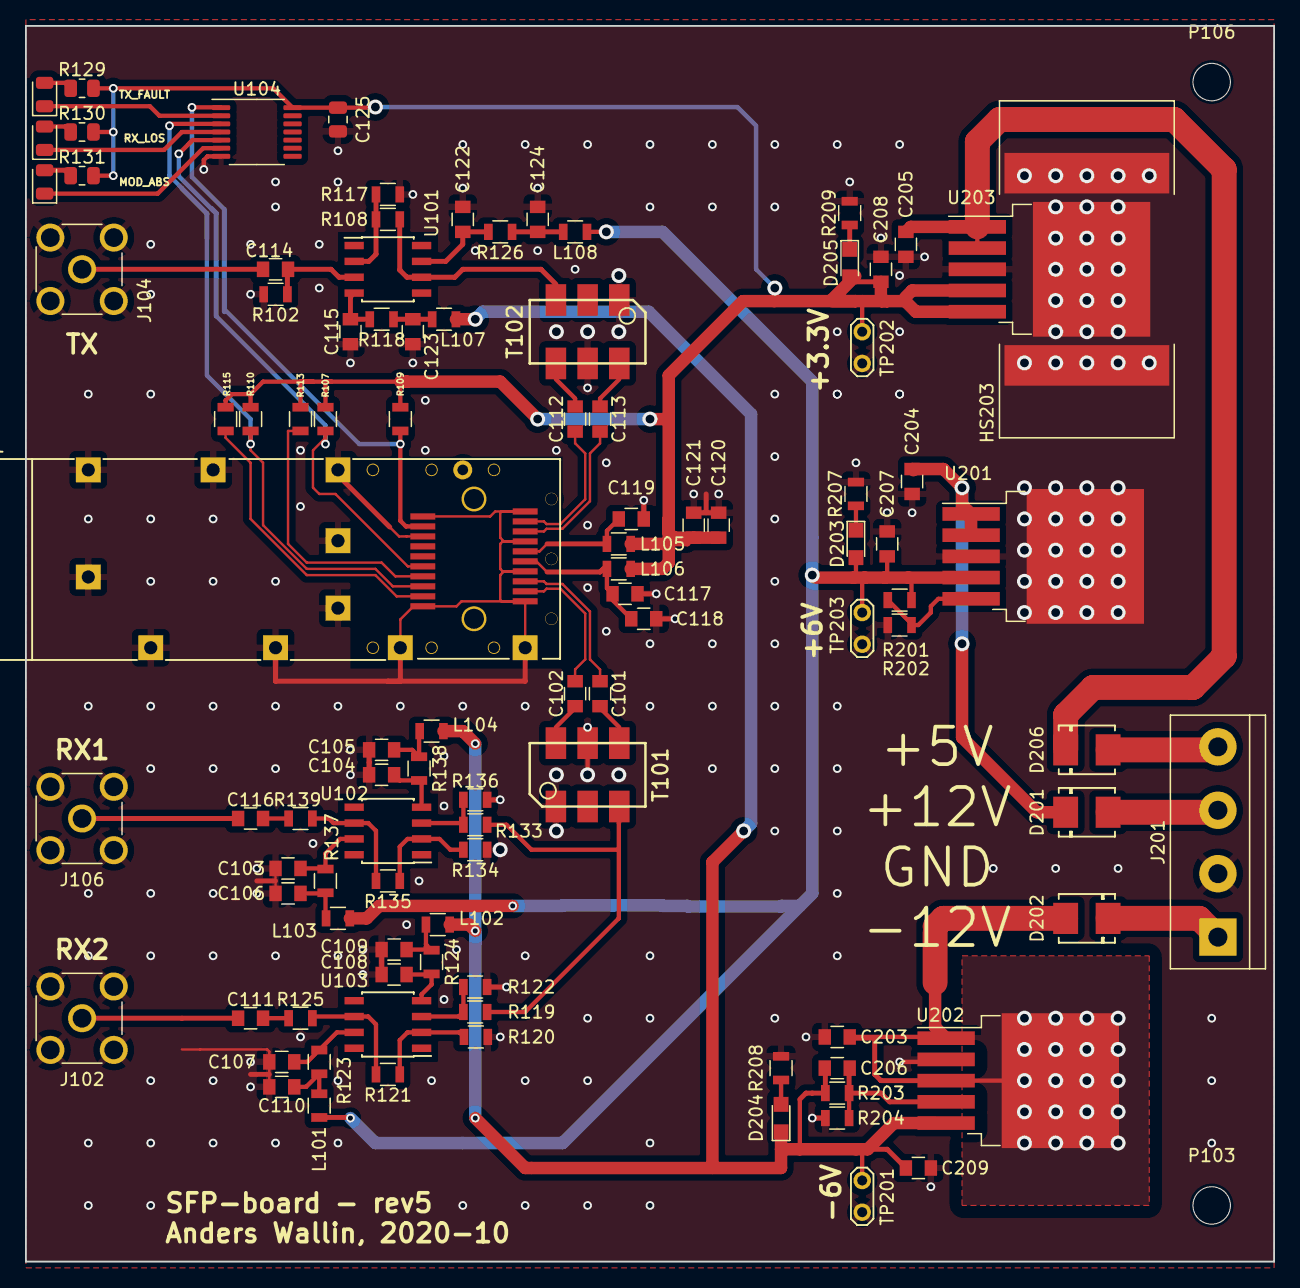
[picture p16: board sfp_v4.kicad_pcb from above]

Board: 2 copper layers, 100.0 x 99.0 mm, 103 parts (0 on the bottom side), 63 nets.

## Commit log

2018-10-24 initial commit of sfp2sma design
    [SFP_PSU.sch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]
2019-03-25 osmocom sfp board links
2019-05-25 add missing component values and comments to schematic
    [SFP_PSU.sch, sfp_v4.sch]
2020-10-22 revise: kicad standard lib symbols/footprints, add SFP status LEDs
    [SFP_PSU.sch, sfp_v4.kicad_pcb, sfp_v4.sch]
2020-10-23 add BOM
    [SFP2SMA_BOM.ods]
2020-10-28 adjust bom
    [SFP2SMA_BOM.ods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]
2020-10-29 tune component values
    [SFP2SMA_BOM.ods, SFP_PSU.sch, sfp_v4.sch]
2020-10-31 minor tuning
    [SFP_PSU.sch, sfp_v4.kicad_pcb, sfp_v4.sch]
2020-11-28 bump gain to 1+240/60
    [sfp_v4.sch]
2020-12-01 adjust values
    [sfp_v4.sch]
2022-12-03 kicad6 version
    [SFP_PSU.kicad_sch, sfp_v4.kicad_pcb, sfp_v4.kicad_sch]
2022-12-03 remove kicad5 files
    [SFP_PSU.sch, sfp_v4.sch]
2025-10-22 update to kicad 9
    [SFP_PSU.kicad_sch, sfp_v4.kicad_pcb, sfp_v4.kicad_sch]
2025-10-22 silk mods
    [sfp_v4.kicad_pcb]
